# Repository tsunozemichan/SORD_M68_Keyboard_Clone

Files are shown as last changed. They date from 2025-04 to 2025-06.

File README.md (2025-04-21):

SORD M68 Keyboard Clone Project

SORD M68のキーボードのクローンを作成するプロジェクトです。

proto04_fix_02が、M68とキーボード部分を仲介するI/F回路のKicadファイルです。

keymatrix03がキーボードのKicadファイルです。
使用しているキースイッチはCherry MX互換です。Cherry MXキースイッチのシンボル、フットプリントは様々なところで入手可能だと思います。

その他の部品のシンボルやフットプリントはLibrary Loaderで入手可能なもののみを使用していると記憶しています。

I/F回路とキーボードの接続はピンソケットになっています。
永続使用には明らかに不便ですので、ご自身で適当なコネクタに変更してください。

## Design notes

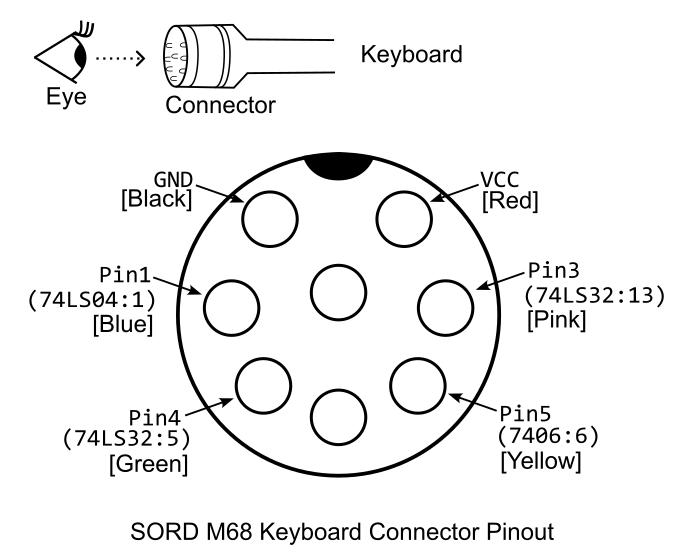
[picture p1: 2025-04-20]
SORD_M68_Keyboard_Socket.png

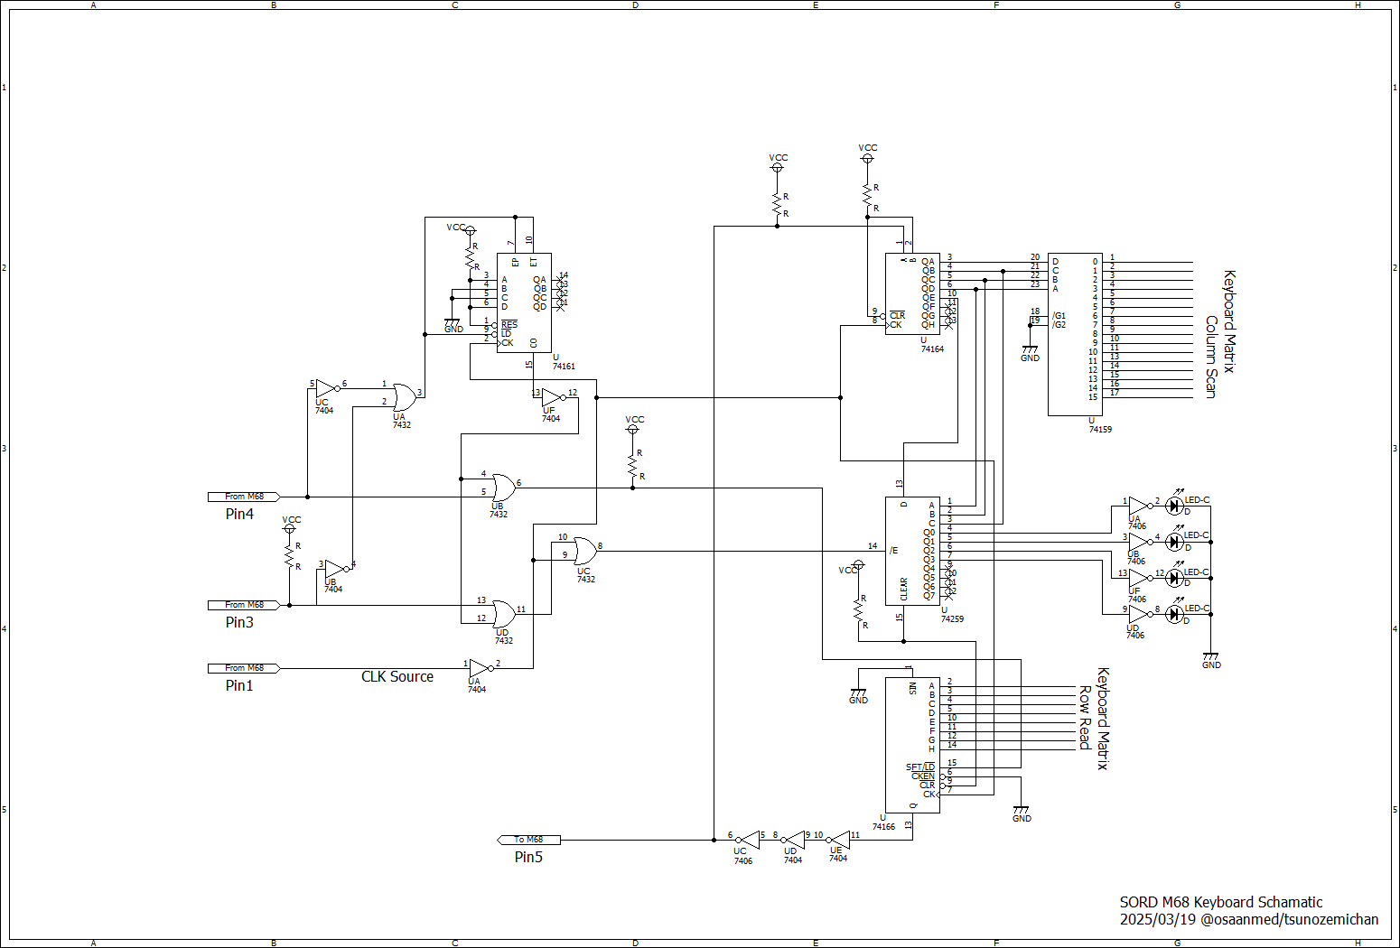
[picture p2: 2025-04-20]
SORD_M68_Keyboard_20250319.png

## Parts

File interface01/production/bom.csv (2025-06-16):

Designator | Footprint | Quantity | Value | LCSC Part #
C1, C2, C3, C4, C5, C6, C7 | C_Disc_D5.0mm_W2.5mm_P2.50mm | 7 | 0.1u
J6 | PinHeader_1x17_P2.54mm_Vertical | 1 | Column
J8 | JST_XH_S6B-XH-A_1x06_P2.50mm_Horizontal | 1 | M68_Kbd_Con
J9 | PinHeader_1x09_P2.54mm_Vertical | 1 | row
R1, R14, R2, R4, R5 | R_Axial_DIN0207_L6.3mm_D2.5mm_P10.16mm_Horizontal | 5 | 4.7k
R10, R11, R12, R13, R6, R7, R8, R9 | R_Axial_DIN0207_L6.3mm_D2.5mm_P10.16mm_Horizontal | 8 | 1k
R3 | R_Axial_DIN0207_L6.3mm_D2.5mm_P10.16mm_Horizontal | 1 | R
U1 | DIP-14_W7.62mm_Socket_LongPads | 1 | 74HC164
U2 | DIP-14_W7.62mm_Socket_LongPads | 1 | 74LS04
U3 | DIP-14_W7.62mm_Socket_LongPads | 1 | 74LS32
U4 | DIP-16_W7.62mm_Socket_LongPads | 1 | 74LS161
U5 | DIP-24_W15.24mm_Socket_LongPads | 1 | 74159
U6 | DIP-16_W7.62mm_Socket_LongPads | 1 | 74LS166
U7 | DIP-14_W7.62mm_Socket_LongPads | 1 | 74LS06

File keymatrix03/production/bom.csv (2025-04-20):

Designator | Footprint | Quantity | Value | LCSC Part #
D1, D10, D11, D12, D13, D14, D15, D16, D17, D18, D19, D2, D20, D21, D22, D23, D24, D25, D26, D27, D28, D29, D3, D30, D31, D32, D33, D34, D35, D36, D37, D38, D39, D4, D40, D41, D42, D43, D44, D45, D46, D47, D48, D49, D5, D50, D51, D52, D53, D54, D55, D56, D57, D58, D59, D6, D60, D61, D62, D63, D64, D65, D66, D67, D68, D69, D7, D70, D71, D72, D73, D8, D9 | D_DO-35_SOD27_P7.62mm_Horizontal | 73 | 1N4148
J1 | PinSocket_1x10_P2.54mm_Horizontal | 1 | To74166
J2 | PinSocket_1x16_P2.54mm_Horizontal | 1 | From74159
SW1 | CherryMX_Red | 1 | ESC
SW10 | CherryMX_Red | 1 | 9
SW11 | CherryMX_Red | 1 | 0
SW12 | CherryMX_Red | 1 | -
SW13 | CherryMX_Red | 1 | ^
SW14 | CherryMX_Red | 1 | \
SW15 | CherryMX_Red | 1 | DEL
SW16 | CherryMX_Red | 1 | TAB
SW17 | CherryMX_Red | 1 | Q
SW18 | CherryMX_Red | 1 | W
SW19 | CherryMX_Red | 1 | E
SW2 | CherryMX_Red | 1 | 1
SW20 | CherryMX_Red | 1 | R
SW21 | CherryMX_Red | 1 | T
SW22 | CherryMX_Red | 1 | Y
SW23 | CherryMX_Red | 1 | U
SW24 | CherryMX_Red | 1 | I
SW25 | CherryMX_Red | 1 | O
SW26 | CherryMX_Red | 1 | P
SW27 | CherryMX_Red | 1 | @
SW28 | CherryMX_Red | 1 | [
SW29 | CherryMX_Red | 1 | RETURN
SW3 | CherryMX_Red | 1 | 2
SW30, SW62 | CherryMX_Red | 2 | CTRL
SW31 | CherryMX_Red | 1 | A
SW32 | CherryMX_Red | 1 | S
SW33 | CherryMX_Red | 1 | D
SW34 | CherryMX_Red | 1 | F
SW35 | CherryMX_Red | 1 | G
SW36 | CherryMX_Red | 1 | H
SW37 | CherryMX_Red | 1 | J
SW38 | CherryMX_Red | 1 | K
SW39 | CherryMX_Red | 1 | L
SW4 | CherryMX_Red | 1 | 3
SW40 | CherryMX_Red | 1 | ;
SW41 | CherryMX_Red | 1 | :
SW42 | CherryMX_Red | 1 | ]
SW43 | CherryMX_Red | 1 | LF
SW44 | CherryMX_Red | 1 | Z
SW45 | CherryMX_Red | 1 | X
SW46 | CherryMX_Red | 1 | C
SW47 | CherryMX_Red | 1 | V
SW48 | CherryMX_Red | 1 | B
SW49 | CherryMX_Red | 1 | SPACE_01
SW5 | CherryMX_Red | 1 | 4
SW50 | CherryMX_Red | 1 | N
SW51 | CherryMX_Red | 1 | M
SW52 | CherryMX_Red | 1 | ,
SW53 | CherryMX_Red | 1 | .
SW54 | CherryMX_Red | 1 | /
SW55 | CherryMX_Red | 1 | _
SW56 | CherryMX_Red | 1 | LEFT
SW57 | CherryMX_Red | 1 | RIGHT
SW58 | CherryMX_Red | 1 | DOWN
SW59 | CherryMX_Red | 1 | UP
SW6 | CherryMX_Red | 1 | 5
SW60 | CherryMX_Red | 1 | S1
SW61 | CherryMX_Red | 1 | S2
SW63 | CherryMX_Red | 1 | SHIFT
SW64 | CherryMX_Red | 1 | SMALL
SW65 | CherryMX_Red | 1 | RESET
SW66 | CherryMX_Red | 1 | KANA
SW67 | CherryMX_Red | 1 | F1
SW68 | CherryMX_Red | 1 | F2
SW69 | CherryMX_Red | 1 | F3
SW7 | CherryMX_Red | 1 | 6
SW70 | CherryMX_Red | 1 | F4
SW71 | CherryMX_Red | 1 | F5
SW72 | CherryMX_Red | 1 | F6
SW73 | CherryMX_Red | 1 | F7
SW8 | CherryMX_Red | 1 | 7
SW9 | CherryMX_Red | 1 | 8

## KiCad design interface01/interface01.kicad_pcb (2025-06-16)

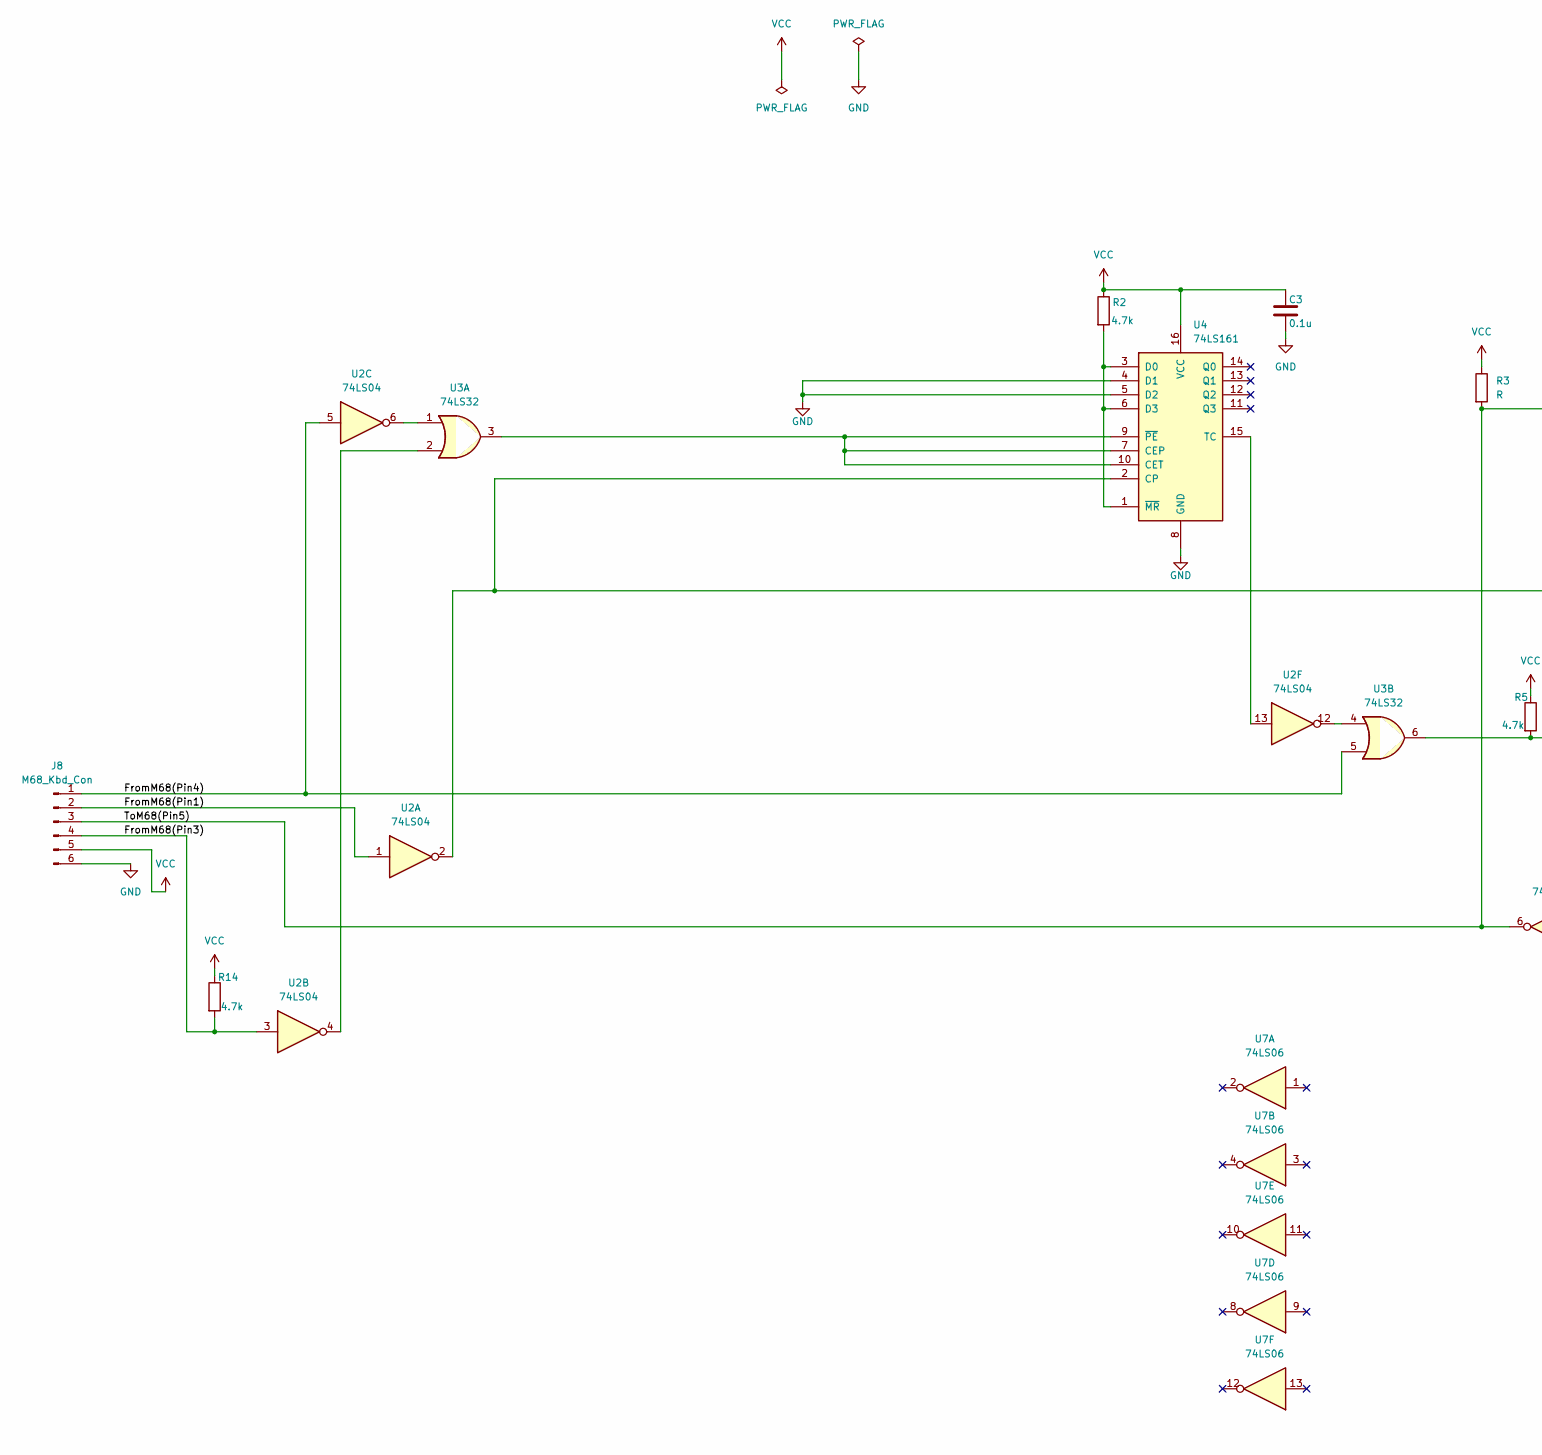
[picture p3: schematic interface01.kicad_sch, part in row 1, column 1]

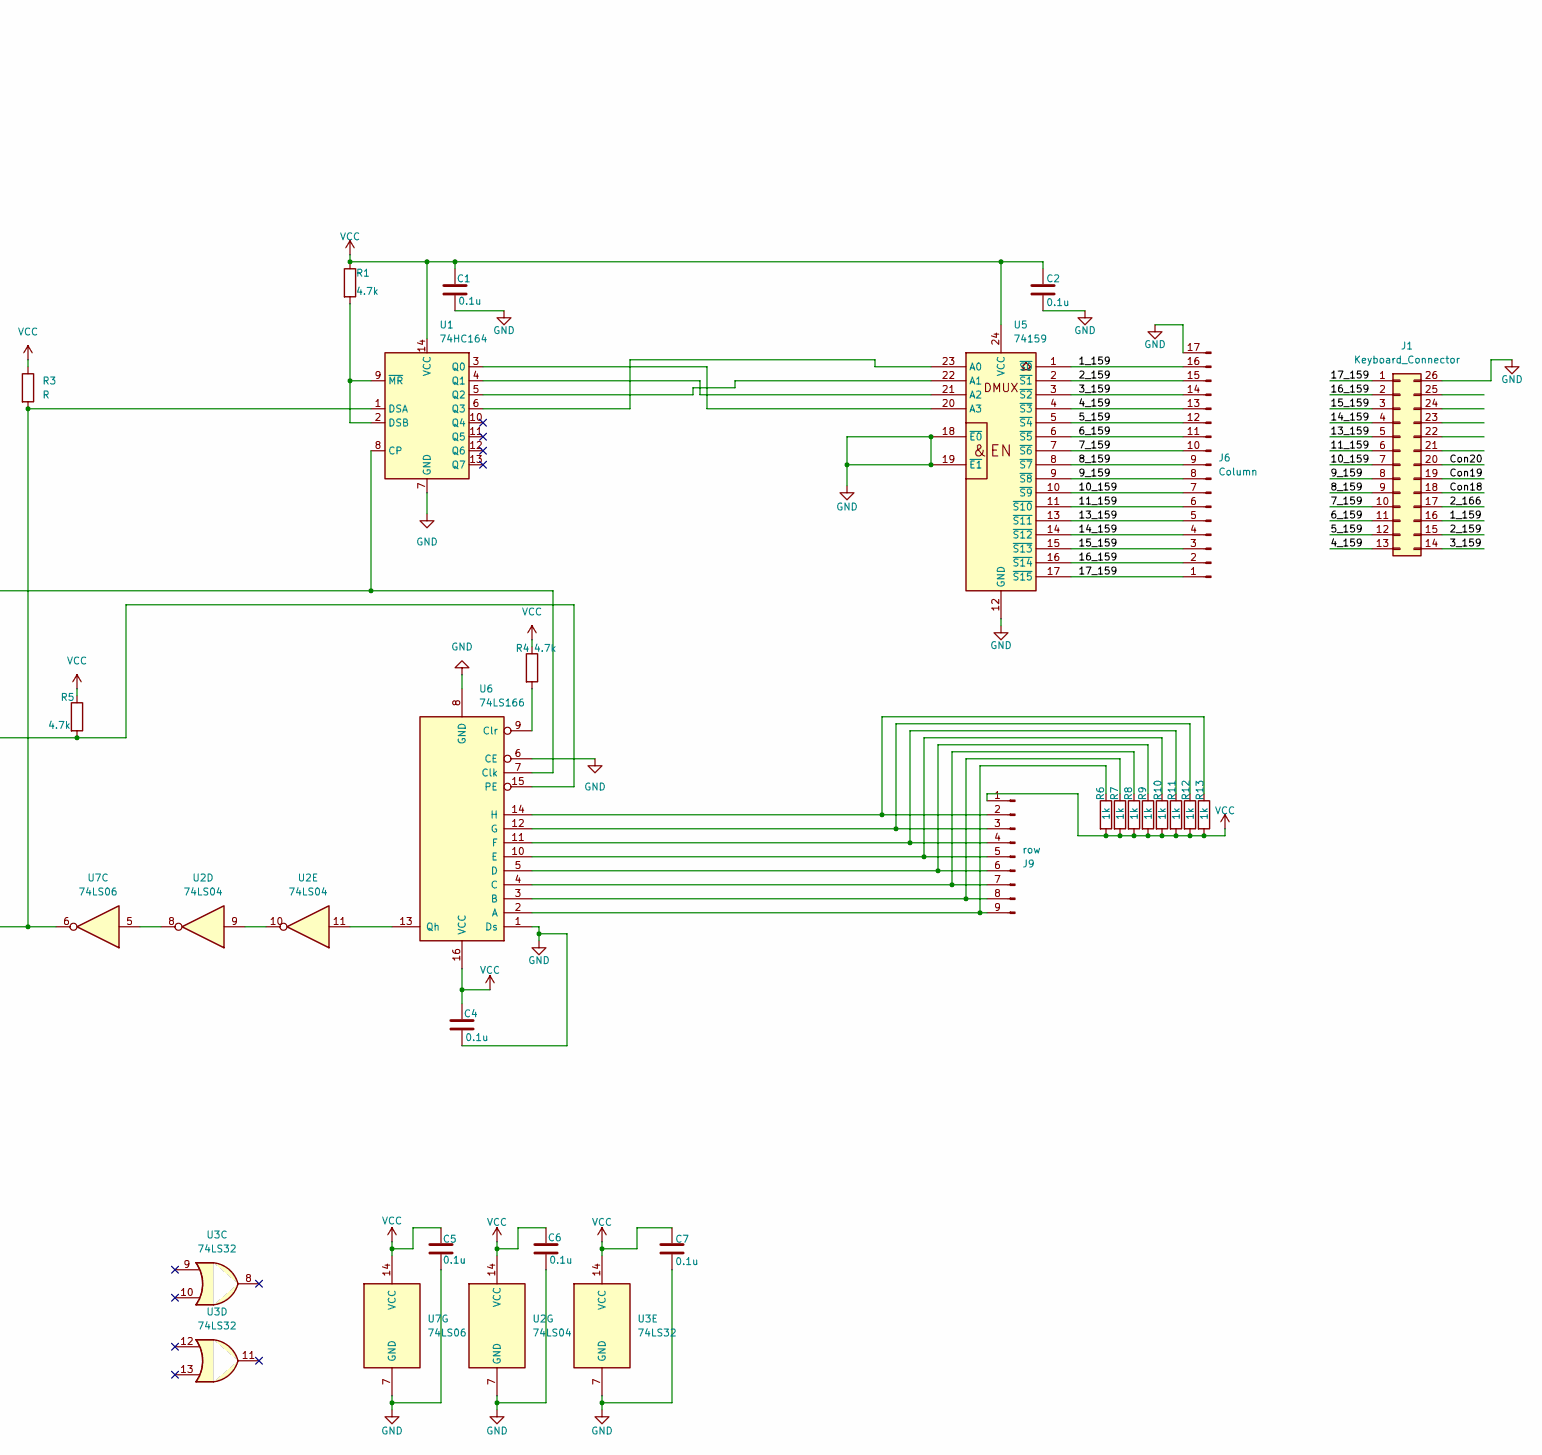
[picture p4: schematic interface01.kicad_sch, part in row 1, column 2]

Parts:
C1, C2, C3, C4, C5, C6, C7: 0.1u; C_Disc_D5.0mm_W2.5mm_P2.50mm
J1: Keyboard_Connector
J6: Column; PinHeader_1x17_P2.54mm_Vertical
J8: M68_Kbd_Con; JST_XH_S6B-XH-A_1x06_P2.50mm_Horizontal
J9: row; PinHeader_1x09_P2.54mm_Vertical
R1, R2, R4, R5, R14: 4.7k; R_Axial_DIN0207_L6.3mm_D2.5mm_P10.16mm_Horizontal
R3: R; R_Axial_DIN0207_L6.3mm_D2.5mm_P10.16mm_Horizontal
R6, R7, R8, R9, R10, R11, R12, R13: 1k; R_Axial_DIN0207_L6.3mm_D2.5mm_P10.16mm_Horizontal
U1: 74HC164; DIP-14_W7.62mm_Socket_LongPads
U2: 74LS04; DIP-14_W7.62mm_Socket_LongPads
U3: 74LS32; DIP-14_W7.62mm_Socket_LongPads
U4: 74LS161; DIP-16_W7.62mm_Socket_LongPads
U5: 74159; DIP-24_W15.24mm_Socket_LongPads
U6: 74LS166; DIP-16_W7.62mm_Socket_LongPads
U7: 74LS06; DIP-14_W7.62mm_Socket_LongPads

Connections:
/FromM68(Pin1): J8.2, U2.1
/FromM68(Pin3): J8.4, R14.2, U2.3
/FromM68(Pin4): J8.1, U2.5, U3.5
/ToM68(Pin5): J8.3, R3.2, U1.1 (DSA), U7.6
GND: C1.2, C2.2, C3.2, C4.2, C5.2, C6.2, C7.2, J1.26, J6.17, J8.6, U1.7 (GND), U2.7 (GND), U3.7 (GND), U4.4 (D1), U4.5 (D2), U4.8 (GND), U5.12 (GND), U5.18 (~E0), U5.19 (~E1), U6.1 (Ds), U6.6 (CE), U6.8 (GND), U7.7 (GND)
unnamed: J1.1, J6.1, U5.17 (~S15)
unnamed: J1.2, J6.2, U5.16 (~S14)
unnamed: J1.3, J6.3, U5.15 (~S13)
unnamed: J1.4, J6.4, U5.14 (~S12)
unnamed: J1.5, J6.5, U5.13 (~S11)
unnamed: J1.6, J6.6, U5.11 (~S10)
unnamed: J1.7, J6.7, U5.10 (~S9)
unnamed: J1.8, J6.8, U5.9 (~S8)
unnamed: J1.9, J6.9, U5.8 (~S7)
unnamed: J1.10, J6.10, U5.7 (~S6)
unnamed: J1.11, J6.11, U5.6 (~S5)
unnamed: J1.12, J6.12, U5.5 (~S4)
unnamed: J1.13, J6.13, U5.4 (~S3)
unnamed: J1.14, J6.14, U5.3 (~S2)
unnamed: J1.15, J6.15, U5.2 (~S1)
unnamed: J1.16, J6.16, U5.1 (~S0)
unnamed: J9.2, R13.1, U6.14 (H)
unnamed: J9.3, R12.1, U6.12 (G)
unnamed: J9.4, R11.1, U6.11 (F)
unnamed: J9.5, R10.1, U6.10 (E)
unnamed: J9.6, R9.1, U6.5 (D)
unnamed: J9.7, R8.1, U6.4 (C)
unnamed: J9.8, R7.1, U6.3 (B)
unnamed: J9.9, R6.1, U6.2 (A)
unnamed: U1.8 (CP), U2.2, U4.2 (CP), U6.7 (Clk)
unnamed: R1.2, U1.2 (DSB), U1.9 (~MR)
unnamed: U1.3 (Q0), U5.20 (A3)
unnamed: U1.4 (Q1), U5.21 (A2)
unnamed: U1.5 (Q2), U5.22 (A1)
unnamed: U1.6 (Q3), U5.23 (A0)
unnamed: U2.4, U3.2
unnamed: U2.6, U3.1
unnamed: U2.8, U7.5
unnamed: U2.9, U2.10
unnamed: U2.12, U3.4
unnamed: U3.3, U4.7 (CEP), U4.9 (~PE), U4.10 (CET)
unnamed: R2.2, U4.1 (~MR), U4.3 (D0), U4.6 (D3)
unnamed: U2.13, U4.15 (TC)
unnamed: R4.2, U6.9 (Clr)
unnamed: R5.2, U3.6, U6.15 (PE)
unnamed: U2.11, U6.13 (Qh)
VCC: C1.1, C2.1, C3.1, C4.1, C5.1, C6.1, C7.1, J8.5, J9.1, R1.1, R2.1, R3.1, R4.1, R5.1, R6.2, R7.2, R8.2, R9.2, R10.2, R11.2, R12.2, R13.2, R14.1, U1.14 (VCC), U2.14 (VCC), U3.14 (VCC), U4.16 (VCC), U5.24 (VCC), U6.16 (VCC), U7.14 (VCC)

Board: 2 copper layers, 31 parts (0 on the bottom side), 47 nets, no tracks yet.

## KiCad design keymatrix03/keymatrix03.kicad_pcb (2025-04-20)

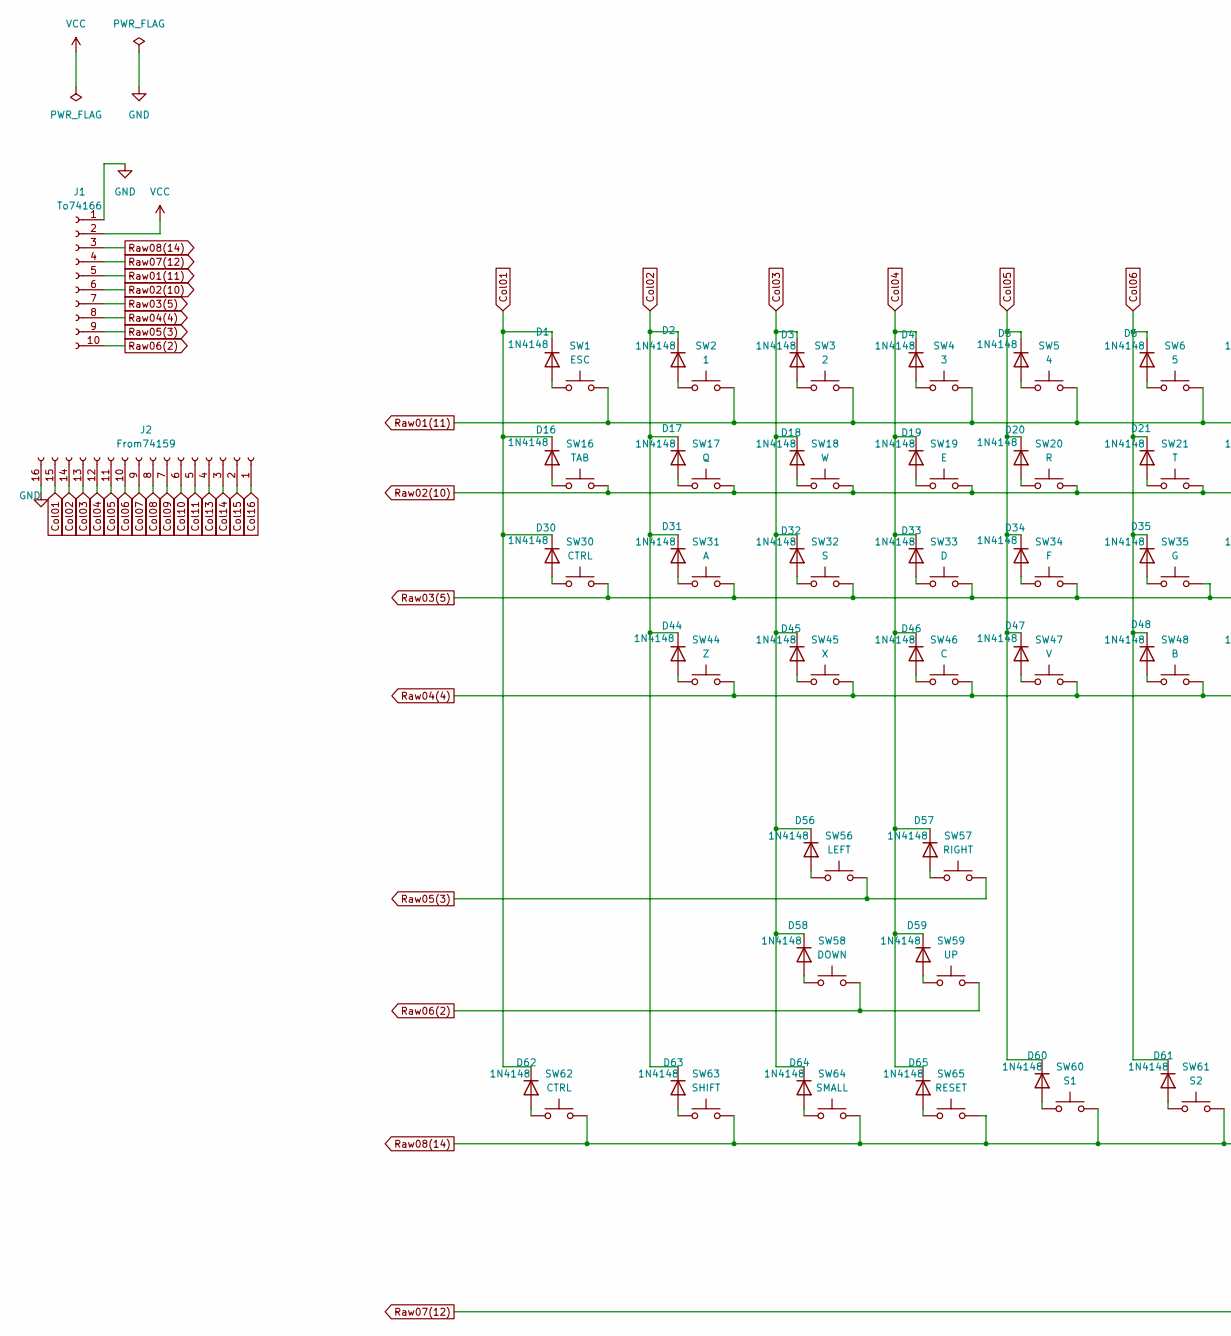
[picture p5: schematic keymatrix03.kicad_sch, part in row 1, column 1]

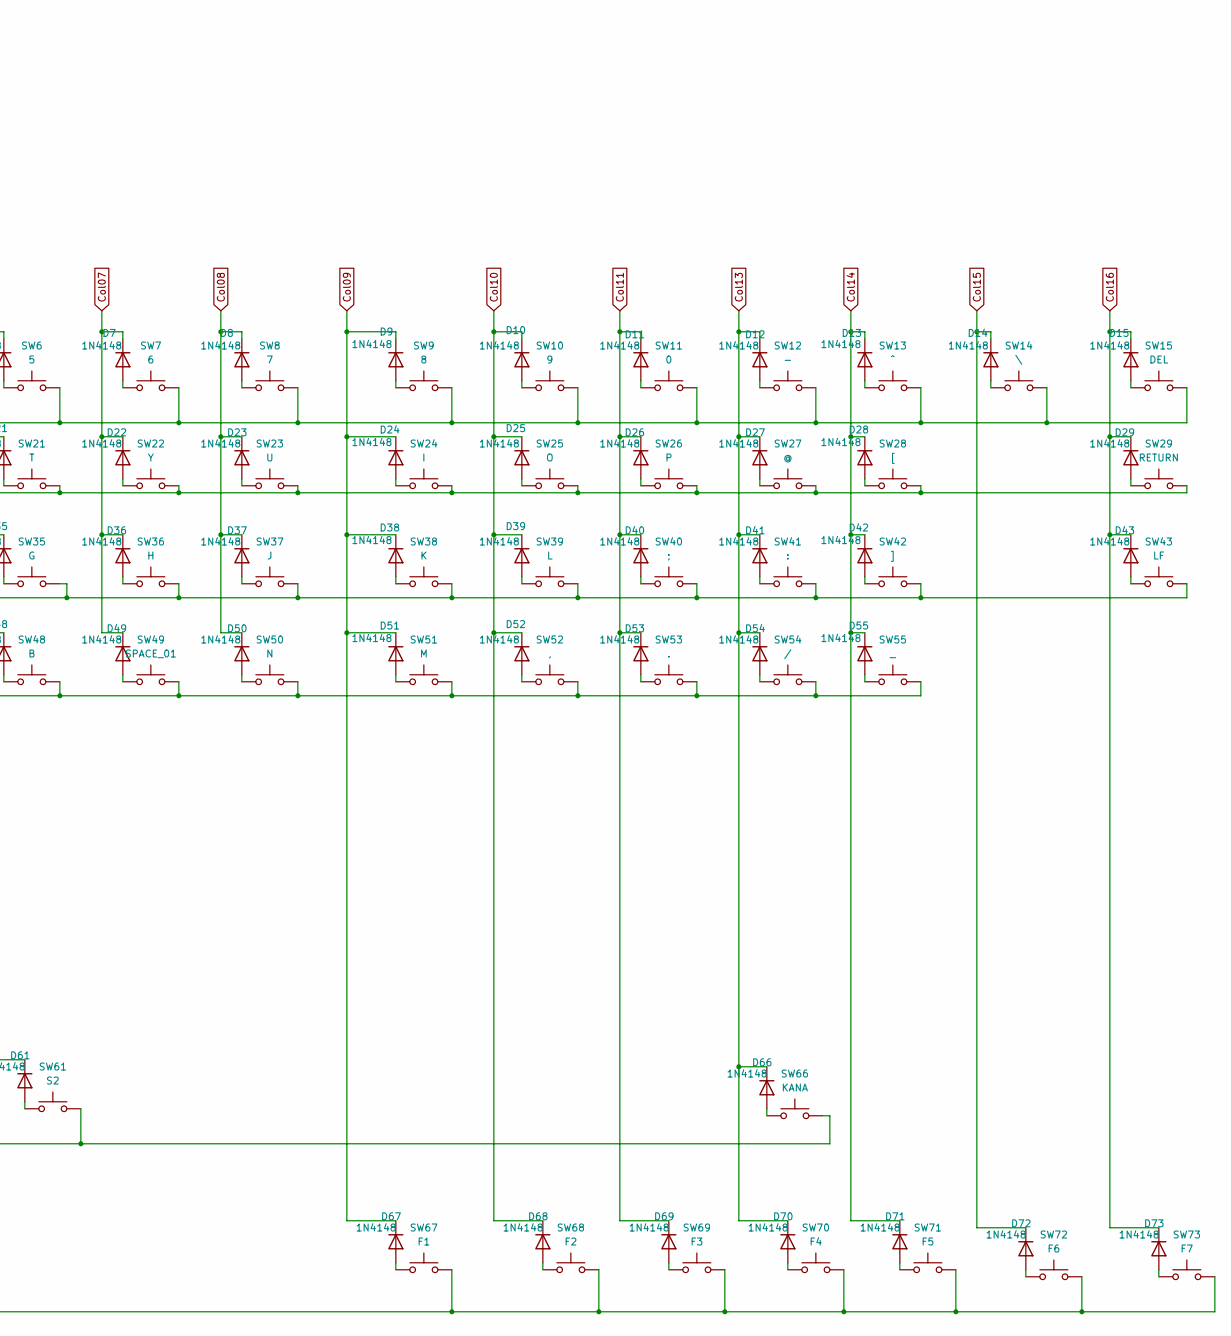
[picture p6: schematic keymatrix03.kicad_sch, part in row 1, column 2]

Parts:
D1, D2, D3, D4, D5, D6, D7, D8, D9, D10, D11, D12, D13, D14, D15, D16, D17, D18, D19, D20, D21, D22, D23, D24, D25, D26, D27, D28, D29, D30, D31, D32, D33, D34, D35, D36, D37, D38, D39, D40, D41, D42, D43, D44, D45, D46, D47, D48, D49, D50, D51, D52, D53, D54, D55, D56, D57, D58, D59, D60, D61, D62, D63, D64, D65, D66, D67, D68, D69, D70, D71, D72, D73: 1N4148; D_DO-35_SOD27_P7.62mm_Horizontal
J1: To74166; PinSocket_1x10_P2.54mm_Horizontal
J2: From74159; PinSocket_1x16_P2.54mm_Horizontal
SW1: ESC; CherryMX_Red
SW2: 1; CherryMX_Red
SW3: 2; CherryMX_Red
SW4: 3; CherryMX_Red
SW5: 4; CherryMX_Red
SW6: 5; CherryMX_Red
SW7: 6; CherryMX_Red
SW8: 7; CherryMX_Red
SW9: 8; CherryMX_Red
SW10: 9; CherryMX_Red
SW11: 0; CherryMX_Red
SW12: -; CherryMX_Red
SW13: ^; CherryMX_Red
SW14: \; CherryMX_Red
SW15: DEL; CherryMX_Red
SW16: TAB; CherryMX_Red
SW17: Q; CherryMX_Red
SW18: W; CherryMX_Red
SW19: E; CherryMX_Red
SW20: R; CherryMX_Red
SW21: T; CherryMX_Red
SW22: Y; CherryMX_Red
SW23: U; CherryMX_Red
SW24: I; CherryMX_Red
SW25: O; CherryMX_Red
SW26: P; CherryMX_Red
SW27: @; CherryMX_Red
SW28: [; CherryMX_Red
SW29: RETURN; CherryMX_Red
SW30, SW62: CTRL; CherryMX_Red
SW31: A; CherryMX_Red
SW32: S; CherryMX_Red
SW33: D; CherryMX_Red
SW34: F; CherryMX_Red
SW35: G; CherryMX_Red
SW36: H; CherryMX_Red
SW37: J; CherryMX_Red
SW38: K; CherryMX_Red
SW39: L; CherryMX_Red
SW40: ;; CherryMX_Red
SW41: :; CherryMX_Red
SW42: ]; CherryMX_Red
SW43: LF; CherryMX_Red
SW44: Z; CherryMX_Red
SW45: X; CherryMX_Red
SW46: C; CherryMX_Red
SW47: V; CherryMX_Red
SW48: B; CherryMX_Red
SW49: SPACE_01; CherryMX_Red
SW50: N; CherryMX_Red
SW51: M; CherryMX_Red
SW52: ,; CherryMX_Red
SW53: .; CherryMX_Red
SW54: /; CherryMX_Red
SW55: _; CherryMX_Red
SW56: LEFT; CherryMX_Red
SW57: RIGHT; CherryMX_Red
SW58: DOWN; CherryMX_Red
SW59: UP; CherryMX_Red
SW60: S1; CherryMX_Red
SW61: S2; CherryMX_Red
SW63: SHIFT; CherryMX_Red
SW64: SMALL; CherryMX_Red
SW65: RESET; CherryMX_Red
SW66: KANA; CherryMX_Red
SW67: F1; CherryMX_Red
SW68: F2; CherryMX_Red
SW69: F3; CherryMX_Red
SW70: F4; CherryMX_Red
SW71: F5; CherryMX_Red
SW72: F6; CherryMX_Red
SW73: F7; CherryMX_Red

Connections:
Col01: D1.1 (K), D16.1 (K), D30.1 (K), D62.1 (K), J2.15
Col02: D2.1 (K), D17.1 (K), D31.1 (K), D44.1 (K), D63.1 (K), J2.14
Col03: D3.1 (K), D18.1 (K), D32.1 (K), D45.1 (K), D56.1 (K), D58.1 (K), D64.1 (K), J2.13
Col04: D4.1 (K), D19.1 (K), D33.1 (K), D46.1 (K), D57.1 (K), D59.1 (K), D65.1 (K), J2.12
Col05: D5.1 (K), D20.1 (K), D34.1 (K), D47.1 (K), D60.1 (K), J2.11
Col06: D6.1 (K), D21.1 (K), D35.1 (K), D48.1 (K), D61.1 (K), J2.10
Col07: D7.1 (K), D22.1 (K), D36.1 (K), D49.1 (K), J2.9
Col08: D8.1 (K), D23.1 (K), D37.1 (K), D50.1 (K), J2.8
Col09: D9.1 (K), D24.1 (K), D38.1 (K), D51.1 (K), D67.1 (K), J2.7
Col10: D10.1 (K), D25.1 (K), D39.1 (K), D52.1 (K), D68.1 (K), J2.6
Col11: D11.1 (K), D26.1 (K), D40.1 (K), D53.1 (K), D69.1 (K), J2.5
Col13: D12.1 (K), D27.1 (K), D41.1 (K), D54.1 (K), D66.1 (K), D70.1 (K), J2.4
Col14: D13.1 (K), D28.1 (K), D42.1 (K), D55.1 (K), D71.1 (K), J2.3
Col15: D14.1 (K), D72.1 (K), J2.2
Col16: D15.1 (K), D29.1 (K), D43.1 (K), D73.1 (K), J2.1
GND: J1.1, J2.16
unnamed: D1.2 (A), SW1.1
unnamed: D2.2 (A), SW2.1
unnamed: D3.2 (A), SW3.1
unnamed: D4.2 (A), SW4.1
unnamed: D5.2 (A), SW5.1
unnamed: D6.2 (A), SW6.1
unnamed: D7.2 (A), SW7.1
unnamed: D8.2 (A), SW8.1
unnamed: D9.2 (A), SW9.1
unnamed: D10.2 (A), SW10.1
unnamed: D11.2 (A), SW11.1
unnamed: D12.2 (A), SW12.1
unnamed: D13.2 (A), SW13.1
unnamed: D14.2 (A), SW14.1
unnamed: D15.2 (A), SW15.1
unnamed: D16.2 (A), SW16.1
unnamed: D17.2 (A), SW17.1
unnamed: D18.2 (A), SW18.1
unnamed: D19.2 (A), SW19.1
unnamed: D20.2 (A), SW20.1
unnamed: D21.2 (A), SW21.1
unnamed: D22.2 (A), SW22.1
unnamed: D23.2 (A), SW23.1
unnamed: D24.2 (A), SW24.1
unnamed: D25.2 (A), SW25.1
unnamed: D26.2 (A), SW26.1
unnamed: D27.2 (A), SW27.1
unnamed: D28.2 (A), SW28.1
unnamed: D29.2 (A), SW29.1
unnamed: D30.2 (A), SW30.1
unnamed: D31.2 (A), SW31.1
unnamed: D32.2 (A), SW32.1
unnamed: D33.2 (A), SW33.1
unnamed: D34.2 (A), SW34.1
unnamed: D35.2 (A), SW35.1
unnamed: D36.2 (A), SW36.1
unnamed: D37.2 (A), SW37.1
unnamed: D38.2 (A), SW38.1
unnamed: D39.2 (A), SW39.1
unnamed: D40.2 (A), SW40.1
unnamed: D41.2 (A), SW41.1
unnamed: D42.2 (A), SW42.1
unnamed: D43.2 (A), SW43.1
unnamed: D44.2 (A), SW44.1
unnamed: D45.2 (A), SW45.1
unnamed: D46.2 (A), SW46.1
unnamed: D47.2 (A), SW47.1
unnamed: D48.2 (A), SW48.1
unnamed: D49.2 (A), SW49.1
unnamed: D50.2 (A), SW50.1
unnamed: D51.2 (A), SW51.1
unnamed: D52.2 (A), SW52.1
unnamed: D53.2 (A), SW53.1
unnamed: D54.2 (A), SW54.1
unnamed: D55.2 (A), SW55.1
unnamed: D56.2 (A), SW56.1
unnamed: D57.2 (A), SW57.1
unnamed: D58.2 (A), SW58.1
unnamed: D59.2 (A), SW59.1
unnamed: D60.2 (A), SW60.1
unnamed: D61.2 (A), SW61.1
unnamed: D62.2 (A), SW62.1
unnamed: D63.2 (A), SW63.1
unnamed: D64.2 (A), SW64.1
unnamed: D65.2 (A), SW65.1
unnamed: D66.2 (A), SW66.1
unnamed: D67.2 (A), SW67.1
unnamed: D68.2 (A), SW68.1
unnamed: D69.2 (A), SW69.1
unnamed: D70.2 (A), SW70.1
unnamed: D71.2 (A), SW71.1
unnamed: D72.2 (A), SW72.1
unnamed: D73.2 (A), SW73.1
Raw01(11): J1.5, SW1.2, SW2.2, SW3.2, SW4.2, SW5.2, SW6.2, SW7.2, SW8.2, SW9.2, SW10.2, SW11.2, SW12.2, SW13.2, SW14.2, SW15.2
Raw02(10): J1.6, SW16.2, SW17.2, SW18.2, SW19.2, SW20.2, SW21.2, SW22.2, SW23.2, SW24.2, SW25.2, SW26.2, SW27.2, SW28.2, SW29.2
Raw03(5): J1.7, SW30.2, SW31.2, SW32.2, SW33.2, SW34.2, SW35.2, SW36.2, SW37.2, SW38.2, SW39.2, SW40.2, SW41.2, SW42.2, SW43.2
Raw04(4): J1.8, SW44.2, SW45.2, SW46.2, SW47.2, SW48.2, SW49.2, SW50.2, SW51.2, SW52.2, SW53.2, SW54.2, SW55.2
Raw05(3): J1.9, SW56.2, SW57.2
Raw06(2): J1.10, SW58.2, SW59.2
Raw07(12): J1.4, SW67.2, SW68.2, SW69.2, SW70.2, SW71.2, SW72.2, SW73.2
Raw08(14): J1.3, SW60.2, SW61.2, SW62.2, SW63.2, SW64.2, SW65.2, SW66.2
VCC: J1.2

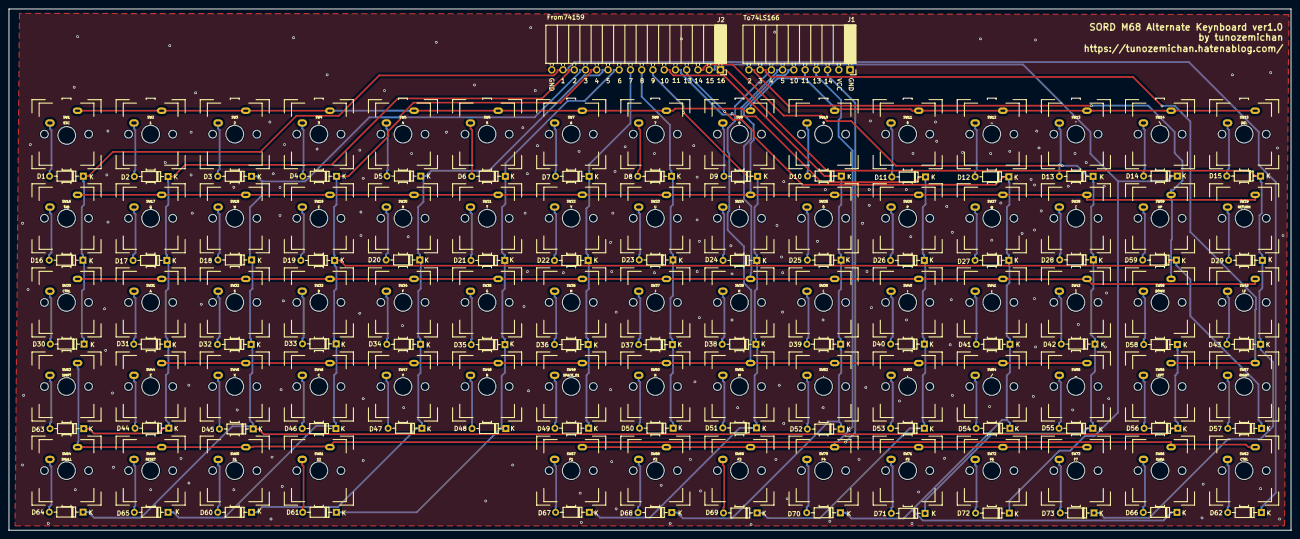
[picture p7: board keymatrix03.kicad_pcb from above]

Board: 2 copper layers, 289.6 x 117.8 mm, 148 parts (0 on the bottom side), 97 nets.

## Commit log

2025-04-20 Add files via upload
    First Release version. This version has been tested on a real device.
    [bom.csv, designators.csv, positions.csv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]
2025-06-16 add interface01
    [bom.csv, designators.csv, interface01.kicad_pcb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]
